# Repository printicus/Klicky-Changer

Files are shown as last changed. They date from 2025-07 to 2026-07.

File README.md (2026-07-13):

# Klicky-Changer 

If you use original KTC from V's github dont go past Klipper v0.13.0-669. For this use the folowing:

```
sudo service klipper stop
cd ~/klipper
git checkout fb57d59ce0aeebfe63d0f7c5d716ee9119faf029
sudo service klipper start
```
After that, if you have a klipper warning, do a "soft reset" not "hard reset", or you will need to reinstall all other addons.

### (fully functional, thing are still being added, modified...)
 
Short demo print featuring [Miniburner XL Toolhead](https://github.com/printicus/For-Voron-Printers/tree/main/MiniBurner_XL_Toolhead).

Test Print (https://www.youtube.com/watch?v=o_eyPX9v53s)

50 toolchanges demo

Test Print (https://youtu.be/J430dFG2X50)

[DISCORD INVITE](https://discord.gg/PGrTdSWV) or [DISCORD CHANNEL](https://discord.com/channels/1119433664799965186/1412843406224523347)

Klicky-Changer is a toolchanger hardware addon for Voron 2.4 and other similar setups, what uses Klicky Probe(or PCB Klicky) as Z probe. Its inspired from the three pin shuttle and backplate interlocking design from [DraftShift Design](https://github.com/DraftShift/StealthChanger) and uses Viesturz's [klipper-toolchanger](https://github.com/viesturz/klipper-toolchanger) software and modified [Klicky-Probe]( https://github.com/jlas1/Klicky-Probe ) configs.

Thanks to the above mentioned sources for my inspiration, without their work my days would be much empty.

This is a ME project. I designet, remixed or modded these files for me, but I uploaded them here, maybe someone will find them interesting and will want to use them. I use Super Slicer as my slicer of choice, wich has an option for "Vertical Hole shrinking compensation" that allows me to tune vertical holes diameter without modifying other dimensions. This will make the vertical holes a bit smaller when my files are used with other slicers, especially for screw holes ment for selftapping. Be aware of that, or parts will break!

I included a file for vertical hole tuning if you want to do that.

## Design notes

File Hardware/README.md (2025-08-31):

# Klicky-Changer hardware parts

Klicky Changer (https://www.youtube.com/watch?v=5xcj8SzUP70)

## Here you can find the designs for the Klicky-Changer hardware parts.

There is a shuttle for using with classic Klicky-Probe and a shuttle for using with PCB Klicky.
The PCB (from the PCK Klicky kit)that has the JST connector must be modified. Because of space constraints the connector must pe removed(just the plastic part), the pins shortened and the wires that come from the pogopins will be soldered direct on the pins(see picture)

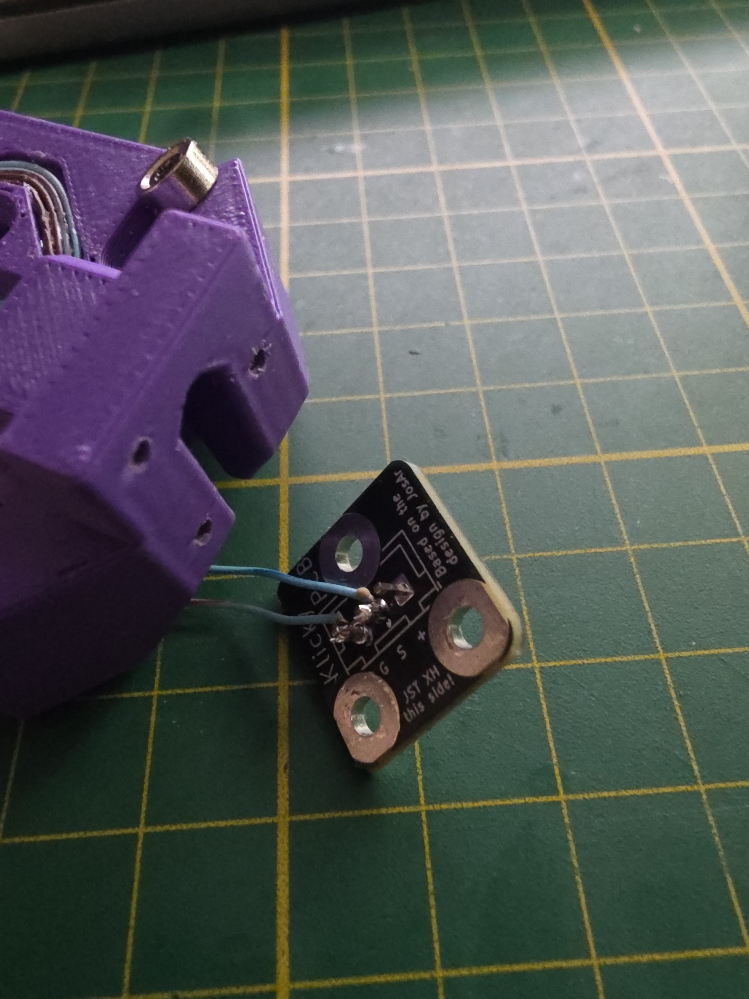
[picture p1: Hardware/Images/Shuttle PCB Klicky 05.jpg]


After some testing I decidet to go with magnets ment to be screwed on, rather than forced into the printed parts. Printed parts tend to loosen over time and the magnets are puled out after repeated use. Glue does not do much.

I gave the option to use double the magnets between the shuttle and backplate. You can choose if you use two pairs or four pairs, depending on what strengt magnets you have. In a normal case, just two magnets on the shuttle, one on each side, and two magnets on the backplate is enough.

The electrical connection between shuttle and backplate is done with pogopins. This is for wireing the Z-probe connection, x-endstop(if you will use it) and for pin detection.

## Pin Detection

For that I use 4 of the 8 pogopins contacts. On the shuttle side solder 4 pogopins together. On the backplate side the corespondent pogopins are soldered 2 and 2. I do this so I will double the contacts uset for tool detection. I dont want after 10 hours printing to get a bad contact and scrap the print. Because I dont use filament detection, the pins for that I use for tool detection. You can use whatever free pins you have on your toolboard.

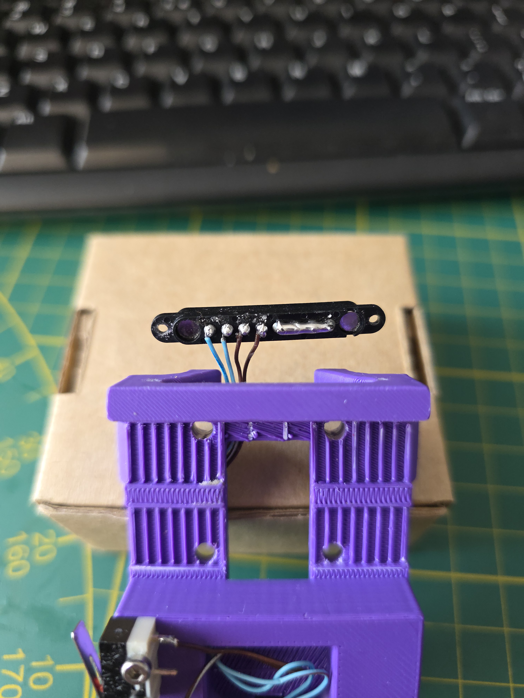
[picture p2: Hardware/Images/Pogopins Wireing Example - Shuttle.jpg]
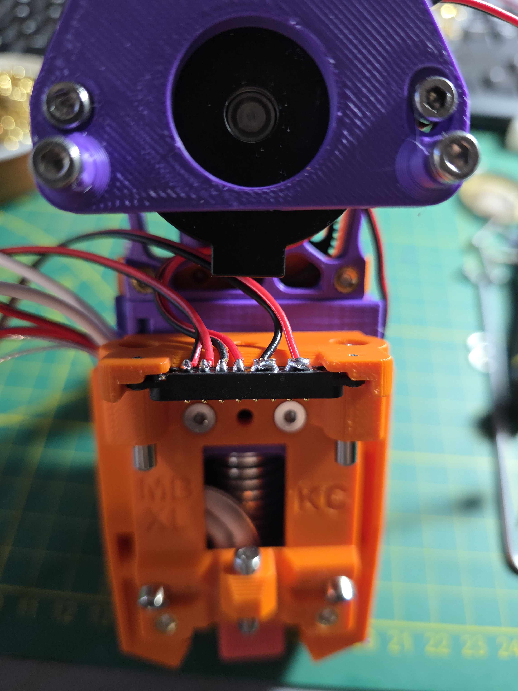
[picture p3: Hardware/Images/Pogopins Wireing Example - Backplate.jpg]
  

## Bom for one shuttle:

- Filament: ABS or ASA
- Endstop switch D2F-L x2 (when used for x endstop the lever stays on, when used for Klicky-Probe the lever must be removed)
- Magnets: 6x3x2mm magnets  x7. This does not include the magnets on the probe itself.
- M2x10  x7 Countersunk Self Tapping Screws for magnets
- Pogopins with 8 contacts. They are sold in pairs. On the shuttle will be used the non springy ones.
- M1.5x4  x2 Self Tapping Screws for the pogopins.
- Thin wires. I've measured them as 0.6mm.
- 4x6x6 Bushings  x3 (Cheap items, buy more than you need and try them out until you find a set that works the best....)

## Bom for probes: BOM can be found on theyr respective Github.

From Klicky Probe github you will need to print the probe and the probe dock(the probe dock will be used allso for PCB-Klicky)
From the PCB-Klicky github you will need to print the probe.

## Links:

- Magnets:  https://www.buyneomagnets.com/p/6mm-dia-x-3mm-thick-with-countersunk-hole-2mm-n35-strong-countersunk-neodymium-disc-magnets-countersunk-ring-rare-earth-magnet

- Endstop switch: https://vi.aliexpress.com/item/1005005222652017.html

- Bushings: https://vi.aliexpress.com/item/1005005335880614.html

    or https://vi.aliexpress.com/item/1005007954250796.html
  
    or https://vi.aliexpress.com/item/1005005924778460.html

- Pogopins I used:  https://vi.aliexpress.com/item/1005006125313623.html  the model I used is "8P with ear 2.54mm". Buy 1-2 pairs extra, maybe, over time the backplate side ones may get bad... not happened to me yet, but nothing is perfect.

- Screws for pogopins: https://vi.aliexpress.com/item/1005003934120055.html

- Screws for magnets - https://vi.aliexpress.com/item/1005006676743568.html

- PCB Klicky kit: https://vi.aliexpress.com/item/1005005467101449.html
- PCB Klicky Github for printed parts: https://github.com/tanaes/whopping_Voron_mods/tree/main/pcb_klicky

- Klicky-Probe Github for printed parts and guides: https://github.com/jlas1/Klicky-Probe

## Recomendet tools

One set of allen keys, Philips small screw-drivers, box cutter, Drill bits starting at 1mm, Side Cutters, pliers, ruler, calipers, etc

Drill Bits Sets: https://vi.aliexpress.com/item/1005004411348630.html
You will need to make shure the holes for the M1.5 and M2 selftapping screws are the rigt size, or parts will break. For the M1.5 screw I use the 1mm drill bit to redrill the hole and for the M2 I use the 1.5mm drill bit.

## Printing

I use primarely SuperSlicer. My designs are made to take advantage of the "Vertical Hole shrinking compensation" setting in that slicer, that lets me tune vertical hole size without altering other dimensions. So if you will slice my files with other slicers, the vertical holes will come out smaller. The holes ment for self tapping screws are the most problematic in this situation. Maybe you will need to redrill them to fit screws trough. I includet a file for tuning the hole size, if you want to use it.

4 walls, 5 tops, 5 bottoms. 40-50% infill. Only pink color allowed.... :D

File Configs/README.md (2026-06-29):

# Configuring Klicky-Changer for Voron 2.4

## Please read all of this first and then start configuring Klicky-Changer.

## KNOWN LIMITATION(AND DANGER):

- Because of how Klicky-Probe software works, the first move when homing after starting the printer, or after the stepper motors disengaging, is the gantry going up by the value of "safe_z", found in **/Klicky-Probe/klicky-variables.cfg** . This will happen once if you use G28(or "home all" buton on your printer web interface), or it will happen twice if you use G28 XY and G28 Z one after annother. So if it happens that the gantry is stoppend and the stepper motors are disengaged close to your printer max Z hight for some reason ( just started the printer, finished print, some errors by docking and undocking, or any other reasons ) do not home the printer or you'll run the risk of going over your Z hight limit and break something. Please manualy move the toolhead to the center of your x-y axis and carrefully ( after making shure no printed parts are on the printer bed ) use the "UNSAFE_LOWER_GANTRY" macro to lower the gantry to a safer hight. The macro will move the gantry down 20mm. So use it to move the gantry to about the half of your printer Z hight, and then home the printer. Dont use the macro if the toolhead is at bed level, it will crash the toolhead and the shuttle in the bed.

- Homing must be in X-Y-Z sequence. Homing Y-X-Z can lead to colision whit the Klicky-Probe Dock or the magnets from the shuttle can drag the Klicky-Probe down from dock and lead to errors and/or crashes.

- The bed mesh "mesh_min" Y distance value should not be smaller than the probe Y offset value ( [tool_probe T(n)] - "y_offset" ). A value of 25 for the "mesh_min" Y will be ok.

- The QGL Y back probe points value ("points:") should not be bigger than your Y max bed size minus the probe Y offset value ( [tool_probe T(n)] - "y_offset" ). A value of (your bed Y size) minus 40 will be ok.

## Klicky-Changer's functions:

- Its a Toolchanger. You can have as many toolheads your printer can fit, and use them for multicolor and multimaterial printing.
- It uses Klicky-Probe (or PCB Klicky) as a Z-Probe for homing, bed meshing and QGL.
- It uses pin detection for knowing what tool is mounted.
- If you have the posibility for homing with every toolhead(if you have sensorless setup, or microswitches for x and y) you can home and start a print with whatever toolhead is on the shuttle. No need to make shure T0 is on the shuttle to home and start printing.

  [My X-endstop solution](../Configs/The%20X-Endstop.md)

## This is how I have configured my printer.

- [Bed Position](Bed_Position.md)
- This is a configuration for "Z-Probe on all tools and fixet docks", with the tool docks on a aluminium profile placed on the front of the printer(or in a door buffer, if you have one). If you want liftbar you must configure that youself, im not familiar with that.
- This configuration steps are for using Klicky-Changer with [MiniBurner XL Toolhead](https://github.com/printicus/For-Voron-Printers/tree/main/MiniBurner_XL_Toolhead). Klicky-Changer can be used with other toolheads to(no limitation there). The main difference will be dock configuration, and you will need to adapt the backplate to your desired toolhead(or ask me to do it...). For that you will need to refer to the specific toolhead you want to use.
- First do the Klicky-Changer configuration as it is. If you decide to do changes in files and/or configs other than what is mentioned in this guide, you may get errors... I run my printer with this configs for a long time now and i got no errors or crashes.
- Homing is handled by Klicky-Probe homing_overide macro. You can find it in **/Klicky-Probe/klicky-macros.cfg**. As it is now, its set for homing with regular microswitches for X and Y. If you want to use sensorless homing you will need to ad macros for that. The macros must be named "_HOME_X" for sensorless X, and "_HOME_Y" for sensorless Y. Allso you must do the rest of the sensorless homing configuration on your hardware and in your printer.cfg.
- After every file modification do a "firmware restart". Until the configuration is finished allways home with T0.

First, please, do a back-up of your configs.
Have the hardware part sorted out(wireing, shuttle, backplates with toolheads, toolheads docks, klicky-probe dock...)

The printer must have klipper and all configs instaled, and functioning as a printer(for best results I recomand a fresh klipper install). For that refer to your Mainboard documentation and your printer manual. If you already have Klicky-Probe(or PCB-Klicky) hardware installed(the probe dock) it will make this setup easier. Delete all klicky-probe files and configs from your printer config folder, Klicky-Changer comes with its own configs for Klicky-Probe. Allso no Kamp or other pluggins for whatever function you have installed. Those can be addet after Klicky-Changer is fully functional, if you still need them. Klicky-Changer comes with tool priming macro includet(N3MI's Prime_Lines macro).

## [Installing](../Configs/Installing.md)

You will need to set the pins in each toolhead configs for the pins of the toolboard atached to it, and ad toolheads configs for all your toolheads. I only posted two as an example.

You will need to set [Klicky-Probe dock position](https://github.com/jlas1/Klicky-Probe/tree/main/Printers/Voron/v1.8_v2.4_Legacy_Trident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) and all the relevant setting for your setup(bed size, etc) in **/Klicky-Probe/klicky-variables.cfg**

## Setting T0 Probe Z-Offset(the paper sheet method):

- You will need to ad in each tool config the probe Y offset ( [tool_probe T(n)] - "y_offset" ). The value for both shuttles(for Klicky-Probe and PCB-Klicky) is **22.45**.

- G28 - QGL - G28(or use the G32 macro includet, it does the same thing, but with fewer probe docking and undocking)
- Make shure the probe is not atachet to the toolhead.
- Move the toolhead to the middle of the bed, imput "G0 Z0" into the console.
- Put a paper sheet on the bed, under the nozzle. Use the Z-Offset controls in your web interface to bring the nozzle down untill it lightly touches the paper. Adjust the z-offset until you feel a small amount of friction when pushing the paper back and forth. The resulted Z-Offset will be a negative number( for example: -4.2 ). You will put that number in your T0 config under "[tool_probe T0]" - "z_offset:", but as a positive number( for example: 4.2).
- Do a one layer print test for fine tunning the first layer z-offset, and adjust the T0 z-offset value in your T0 config file accordingly.

The formula for finding the new value for Z-offset is: the z-offset from the T0 config-(the new z-offset).
For example: the z-offset from the T0 config is 4.2 and the new z offset after adjusting for better first layer is, lets say, -0.12(how it shows in the web interface z-offset). That results in 4.2-(-0.12), and after math rules its 4.2+0.12=4.32 Thats the new value for T0 z-offset.

Value adjusting in the toolheads configs must be done manually, not with the "save config" command.

After you have a first layer to be proud of, write that Z offset value in all your tools configs([tool_probe T(n)] - "z_offset:")
If you will need to again fine tune the T0 z-offset and it will be a different value(usually a very small difference do to the plastic on the touching points between shuttle and backplate settling after repeated toolchanges) you will need to write the new Z-offset value in all tools configs.

## Setting dock position

## Definition: "docked position" is the toolhead position on the shuttle, inserted in the dock in the correct x an y position, with the toolhead magnets close to the dock magnets, but not touching.

After setting T0 Z-offset, and with T0 on the shuttle:
1. G28 - QGL - G28(or use the G32 macro includet, it does the same thing, but with fewer probe docking and undocking)
2. Using the web interface move your toolhead to his designated dock so that it will be in the "docked position", as precise as you can. Write the X and Y coordonates shown in the Toolhead position on your web interface in your T(n)(n = what number toolhead you have on the shuttle) config, under [tool T(n)] section's "params_park...". For Z coordonates you will need to ad 1mm and do the same. 
3. Carefully backup the toolhead from the dock , and lower the gantry to about 50-100 Z position. Do a "Firmware Restart".
4. After restart, with T0 on the shuttle, do a G32. Manually swap T0 with next toolhead that needs dock setting. Go to step 2. If all toolhead have the dock positiom set, go to step 5.

Usually, when all toolheads and docks are the same model, the Y and Z "docked position" for all toolhead should be the same. But dont rely on this...

5. For testing and safety purposes, change the "params_fast_speed" and "params_path_speed" in the /Klipper-Toolchanger/toolchanger.cfg file to a much lover value. Lets say 5000 and 300. Do a "Firmware Restart". After the testing is done you will revert this change.
6. With T0 on the suttle do a G32. When finished, atempt a toolchange by using the Tools macro. Be ready to catch the toolhead if something goes wrong... Adjust the dock position coordonates if needet untill the toolchanges are done whitout problems.

## Setting the other toolheads(T1, T2, etc) g-code z-offset(not T0)

1. With T0 on the shuttle do a G32. Use the tools macro to do a toolchange for the next tool that needs setting the g-code z-offset. Move the tool to the middle of the bed, input on the console G0 Z1. See if the nozzle is touching the bed. If not, use the web interface to move to toolhead down to Z0 in small steps(0.1mm). 
2. If you got to Z0 and the nozzle is not touching the bed, put a piece of paper under the nozzle and use the z-offset controls to lower the nozzle until it touches the paper. Adjust that until you feel a small amount of friction when pushing the paper back and forth. Go to step 4.
3. If the nozzle is touching the bed before you got to Z0, rise the nozzle with the z-offset controls by 0.1 mm, then lover the nozzle with the tool position controls by 0.1mm. Do this until the toolhead is at Z0 and the nozzle does not touch the bed. Go to step 2.
4. The value shown in the web interface under z-offset is the value you must write in your T(n) tool config in [tool T(n)] section under "gcode_z_offset:" This time the value must be writen as shown in the web interface. Do a "Firmware Restart".
5. If all other toolheads have the g-code z-offset set, next step is X and Y gcode offsets. If not, go to step 1.

You must, as with T0, do a one layer print test with each toolhead to fine tune that first layer. The new value shown in the web interface z-offset position must replace the value in that toolhead gcode z-offset setting.
The gcode z-offset value adjusting in the toolheads configs must be done manually, not with the "save config" command.

## [Slicers](../Configs/Slicers.md)

## Setting the toolheads(T1, T2, etc) g-code X and Y offsets.

The X and Y gcode offsets are needet so that all nozzles after T0(T1, T2, etc) are alignet with T0 nozzle.

Guides on how to do that can be found in the links bellow. 

I use a [nozzle camera](https://github.com/printicus/For-Voron-Printers/tree/main/OV9726%20Nozzle%20Camera) and [Axiscope](https://github.com/nic335/Axiscope) to do that.

But there are allot of other methods:

By printing: https://www.printables.com/model/201707-x-y-and-z-calibration-tool-for-idex-dual-extruder

NozzleAllign - https://github.com/viesturz/NozzleAlign

Nudge - https://github.com/zruncho3d/nudge

kTAMV - https://github.com/TypQxQ/kTAMV

In theory, thats it. Your setup my need some adjustments over time, but its ready to print. Good Luck.

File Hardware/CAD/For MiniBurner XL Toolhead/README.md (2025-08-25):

# This are the parts needet to use my toolhead, MiniBurner XL, with Klicky-Changer.

You can find Miniburner XL Toolhead [HERE](https://github.com/printicus/For-Voron-Printers/tree/main/MiniBurner%20XL%20Toolhead).

## BOM for Dock:
- Filament ABS or ASA
- M3 Heat Inserts x2(voron specs)
- 6x3x2 Magnets x4 - N-S oriented all in the same direction. The pairs for this magnets will be on the toolhead
- M2x10 x4 Countersunk Selftapping Screws for magnets
- M3 Hammerhead T-nuts x2
- M3x8 x4
- Silicon for the silicon pad
- 50x10x0.4 spring steel for the silicon pad.

## BOM for Backplate
- Filament ABS or ASA
- M3 Heat Inserts x2(voron specs)
- M3x4x12 Pins x3 - https://vi.aliexpress.com/item/1005007596796680.html
- M3x10 x2 screws - for the upper pins(see CAD)
- M3x8 x1 screw - for the lower pin
- Pogopins - The pair that comes with the one mounted on the shuttle. On the Backplate will be mounted the one with the springy pins. The pogopins have magnets on both ends, and can be paired only in one direction.
- M1.5x4 x2 Self Tapping Screws for pogopins(the same used on the shuttle) - https://vi.aliexpress.com/item/1005003934120055.html
- 6x3x2 Magnets - two with N-S oriented in one direction and two in the other direction(see picture in Images folder)
                https://www.buyneomagnets.com/p/6mm-dia-x-3mm-thick-with-countersunk-hole-2mm-n35-strong-countersunk-neodymium-disc-magnets-countersunk-ring-rare-earth-magnet
- M2x8 x4 Countersunk Self Tapping Screws for magnets - https://vi.aliexpress.com/item/1005006676743568.html

## Printing:

4 walls, 5 Top layers, 5 Bottom layers, 40-50% infill.

Shuttle and Backplate should be printed in the same XY orientation. No mather how good your printer is, there would allways be a size diference between the same dimension on X and Y.

## For the Shuttle and Backplate - The design gave you the option for 4 pairs of magnets, but you should only use them all if your magnets are weak. No need to use 4 pairs of magnets. For normal use two magnets on the shuttle, one on each side, and two on the backplate are enough.

## Using the silicon mold for Miniburner XL toolchanger dock.

Silicon Mold (https://www.youtube.com/watch?v=6CMpIc2Bso8)

Silicon I used: - https://www.amazon.de/dp/B01MZ7EO1V?ref=ppx_yo2ov_dt_b_fed_asin_title&th=1

Its a very high temp resisting silicon. No release agent needed. It does not stick to annything, and can easy be removed. One or two holes drilled in the springsteel strip before molding it in the pad for the dock, will help.

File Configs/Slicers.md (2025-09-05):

# This is how I have configured my slicers

## **My primary Print_Start is in the slicer.**

## - For Super Slicer:

In your "Filament Settings" tab, in "Multimaterial" settings you must have enabled "ramming for multitool setups". This will make restore your tool after a toolchange on the wipe tower and not the printed part. 

In the Printer Setting tab, under Custom G-code:
 - In the "StartG-code" window I have:

```
BED_MESH_CLEAR
G28 x y
Attach_Probe_Lock
G28 z
G90
G0 X30 Y30 Z100 F20000              ; move nozzle away from bed
M190 S[first_layer_bed_temperature] ; wait for bed temp to stabilize
QUAD_GANTRY_LEVEL
G28
BED_MESH_CLEAR
BED_MESH_CALIBRATE ADAPTIVE=1
Dock_Probe_Unlock
G0 X30 Y30 Z100 F20000              ; move nozzle away from bed
PRINT_START TOOL_TEMP={first_layer_temperature[initial_tool]} {if is_extruder_used[0]}T0_TEMP={first_layer_temperature[0]}{endif} {if is_extruder_used[1]}T1_TEMP={first_layer_temperature[1]}{endif} {if is_extruder_used[2]}T2_TEMP={first_layer_temperature[2]}{endif} {if is_extruder_used[3]}T3_TEMP={first_layer_temperature[3]}{endif} {if is_extruder_used[4]}T4_TEMP={first_layer_temperature[4]}{endif} {if is_extruder_used[5]}T5_TEMP={first_layer_temperature[5]}{endif}  BED_TEMP=[first_layer_bed_temperature] TOOL=[initial_tool]
```

 - In the "Tool change G-code" window I have:

```
{if layer_num > 0}
M104 S{temperature[next_extruder]} T[next_extruder] ; set new tool temperature so it can start heating while changing
{else}
M104 S{first_layer_temperature[next_extruder]} T[next_extruder] ; set new tool temperature so it can start heating while changing
{endif}
M106 S0
T[next_extruder]
{if layer_num > disable_fan_first_layers -1}
M106 S{default_fan_speed *2.55}
{endif}
```

This will start preheating your next tool acording to what layer it will be printing. If you have in your slicer different temps for first layer and the other layers it will preheat accordingly. It will also stop the PCF for the toolchange, so it will not interfere with the temp stabilization, and will start the PCF only at the layer that you have it set in the Filament Settings tab, under Cooling, and at the speed you have it set.

## - For Prusa Slicer:

In your "Filament Settings" tab, in "Advanced" settings you must have enabled "ramming for multitool setups". This will make restore your tool after a toolchange on the wipe tower and not the printed part.

In the Printer Setting tab, under Custom G-code:
 - In the "StartG-code" window I have:

```
BED_MESH_CLEAR
G28 x y
Attach_Probe_Lock
G28 z
G90
G0 X30 Y30 Z100 F20000            ; move nozzle away from bed
M190 S[first_layer_bed_temperature] ; wait for bed temp to stabilize
QUAD_GANTRY_LEVEL
G28
BED_MESH_CLEAR
BED_MESH_CALIBRATE ADAPTIVE=1
Dock_Probe_Unlock
G0 X30 Y30 Z100 F20000         ; move nozzle away from bed
PRINT_START TOOL_TEMP={first_layer_temperature[initial_tool]} {if is_extruder_used[0]}T0_TEMP={first_layer_temperature[0]}{endif} {if is_extruder_used[1]}T1_TEMP={first_layer_temperature[1]}{endif} {if is_extruder_used[2]}T2_TEMP={first_layer_temperature[2]}{endif} {if is_extruder_used[3]}T3_TEMP={first_layer_temperature[3]}{endif} {if is_extruder_used[4]}T4_TEMP={first_layer_temperature[4]}{endif} {if is_extruder_used[5]}T5_TEMP={first_layer_temperature[5]}{endif}  BED_TEMP=[first_layer_bed_temperature] TOOL=[initial_tool]
```

 - In the "Tool change G-code" window I have:

```
{if layer_num > 0}
M104 S{temperature[next_extruder]} T[next_extruder] ; set new tool temperature so it can start heating while changing
{else}
M104 S{first_layer_temperature[next_extruder]} T[next_extruder] ; set new tool temperature so it can start heating while changing
{endif}
M106 S0
T[next_extruder]
{if layer_num > disable_fan_first_layers[current_extruder] -1}
M106 S{min_fan_speed[current_extruder] *2.55}
{endif}
```

This will start preheating your next tool acording to what layer it will be printing. If you have in your slicer different temps for first layer and the other layers it will preheat accordingly. It will also stop the PCF for the toolchange, so it will not interfere with the temp stabilization, and will start the PCF only at the layer that you have it set in the Filament Settings tab, under Cooling, and at the speed you have it set.

## - For Orca Slicer:

In your "Printer/Multimaterial" tab the "Enable filament ramming" option must be enabled. In your filament profiles settings "Multimaterial" tab, the option "Enable ramming for multi-tool setups" must be enabled. This will make restore your tool after a toolchange on the wipe tower and not the printed part.

In the Printer Setting tab, under Machine G-code:
 - In the "Machine startG-code" window I have:

```
BED_MESH_CLEAR
G28 x y
Attach_Probe_Lock
G28 z
G90
G0 X30 Y30 Z100 F20000            ; move nozzle away from bed
M190 S[first_layer_bed_temperature] ; wait for bed temp to stabilize
QUAD_GANTRY_LEVEL
G28
BED_MESH_CLEAR
BED_MESH_CALIBRATE ADAPTIVE=1
Dock_Probe_Unlock
G0 X30 Y30 Z100 F20000         ; move nozzle away from bed
PRINT_START TOOL_TEMP={first_layer_temperature[initial_tool]} {if is_extruder_used[0]}T0_TEMP={first_layer_temperature[0]}{endif} {if is_extruder_used[1]}T1_TEMP={first_layer_temperature[1]}{endif} {if is_extruder_used[2]}T2_TEMP={first_layer_temperature[2]}{endif} {if is_extruder_used[3]}T3_TEMP={first_layer_temperature[3]}{endif} {if is_extruder_used[4]}T4_TEMP={first_layer_temperature[4]}{endif} {if is_extruder_used[5]}T5_TEMP={first_layer_temperature[5]}{endif}  BED_TEMP=[first_layer_bed_temperature] TOOL=[initial_tool]
```

- In the "Change filament G-code" window I have:

```
M106 S0
T[next_extruder]
```

This will stop the PCF for the toolchange, so it will not interfere with the temp stabilization, and generate a toolchange command. The slicer does start the fan after the toolchange.

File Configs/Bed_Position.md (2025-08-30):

The printer bed position should be as in front of the printer as possible. It makes it easy to ad accessories in the back of the printer bed(nozzle scrubbers, klicky-probe dock, nozzle probes, etc).

For this you will home your printer, then move your toolhead to Y0. Make a mark on the XY joints printed parts and on the correspondent gantry extrusion, disengage the stepper motors, manualy move the gantry forward untill it touches the front idlers and measure the distance between the mark on the XY joints printed parts and the mark on the gantry extrusion.

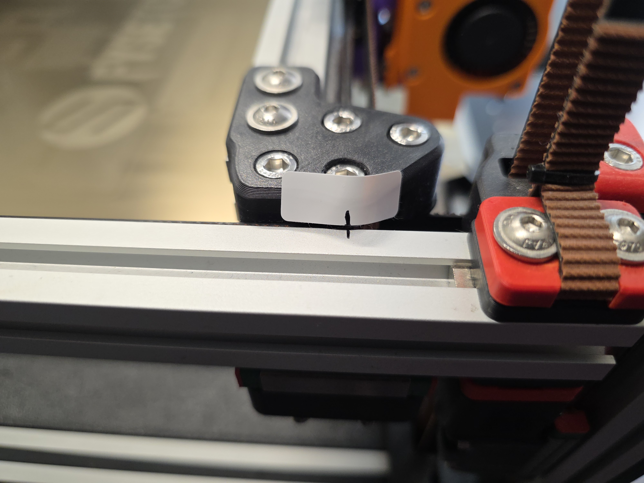
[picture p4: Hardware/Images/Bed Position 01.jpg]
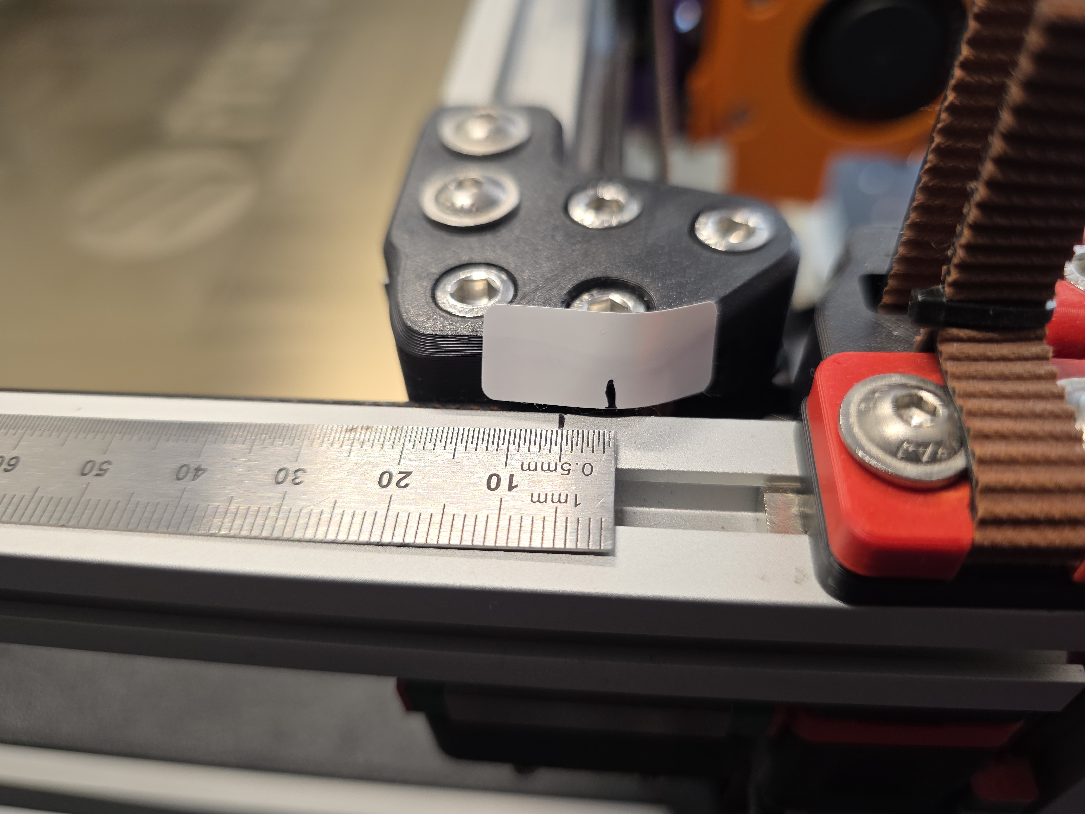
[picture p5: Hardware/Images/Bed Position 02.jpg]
  

That distance measured minus 1mm(you dont want the gantry to slam in the front idlers when going Y0) must be added to the value found in printer.cfg in your Y motor config as "position_endstop:" and "position_max:". All other accessories you allready have configured and depend on Y position must have the Y position corected in their config.

After an "firmware_restart" home the printer, move the toolhead to Y0 and move the bed so that the edge of the bed will coincide with the tip off the nozzle.

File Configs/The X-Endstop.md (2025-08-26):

# The X-Endstop

I have searched a solution for using the microswitch on the shuttle as a X-Endstop for a long time. I did not found the software solution, yet. Klipper does not permit multiple endstops per stepper motor.
So I have gone the hardware route for this:

The original cables for my toolboards where to tick and heavy for what I like, so I build myself other cables. I used for this some PTFE Shielded Cable I found on Aliexpress. The cable I bought has 4 wires(0.35 mm^2) plus the shielding. I used 2 wire for the usb toolboard, 2 wire for x-endstop, I used the shielding for negative voltage and I runned annother PTFE 18AWG wire for plus voltage. As a bonus, the cable is pretty stiff, and, between the stiffnes of the cable and the PTFE tubing for the filament, I dont need to use anny spring wire or flatband to keep the umbilical nice and straight(first asterisk). On the back of the printer I wired all the umbilical x-endstop wires in paralel and connected them to a empty endstop connector on the motherboard. In front, the umbilical x-endstop wires are connected to two of the pogopins that, when atached to the shuttle, are connected to the x-endstop on the shuttle. In this way I have a working X-endstop on the shuttle that works with all toolheads. I hope I did not make annybody dizzy...

Links:
- PTFE Cable 4 wires(0.35 mm^2) - https://vi.aliexpress.com/item/1005007128144063.html
- XT30(2+2)f Connectors - https://vi.aliexpress.com/item/1005008255764206.html
- Extra plus voltage wire - https://vi.aliexpress.com/item/1005001887468108.html
- Molex Connectors - https://vi.aliexpress.com/item/1005005657577507.html

Now, the asterisk:

- First asterisk:

I designet my toolboards mounts so that the cable is tilted towards the back of the printer, so it vill better clear the docks when printing under them. For inforcing that tilt I allso use a 30cm 1.5mm music wire. Pictures are in the Images folder.

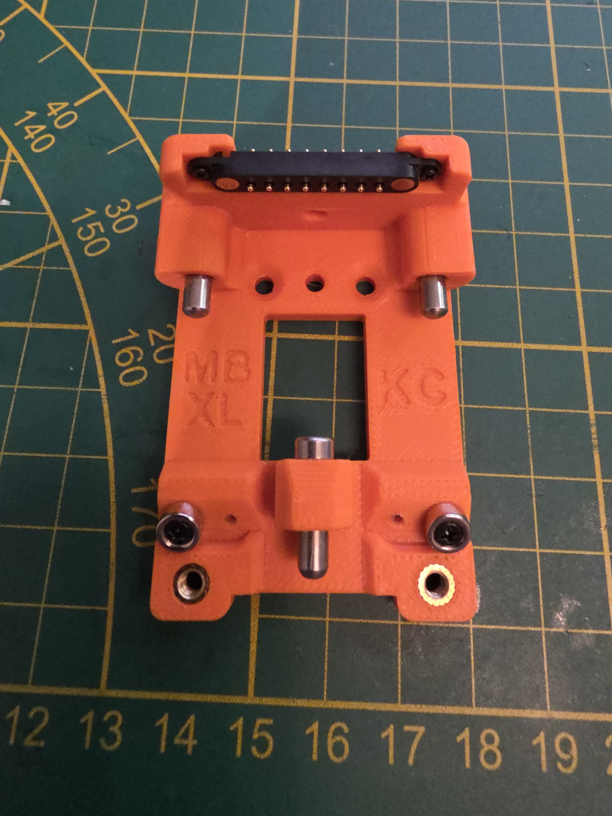
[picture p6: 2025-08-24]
Hardware/CAD/For MiniBurner XL Toolhead/Images/Backplate Miniburner XL 01.jpg

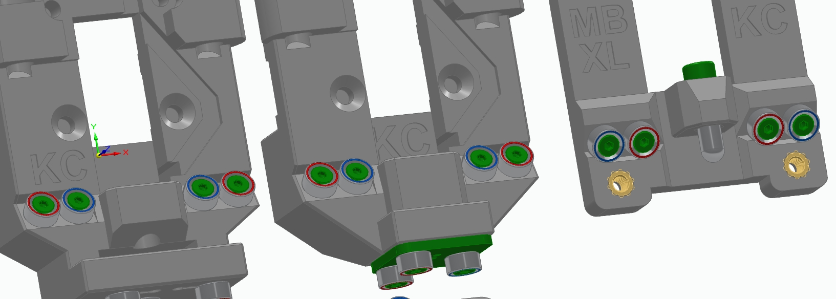
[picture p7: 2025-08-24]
Hardware/Images/Shuttle-Backplate Magnets Orientation.jpg

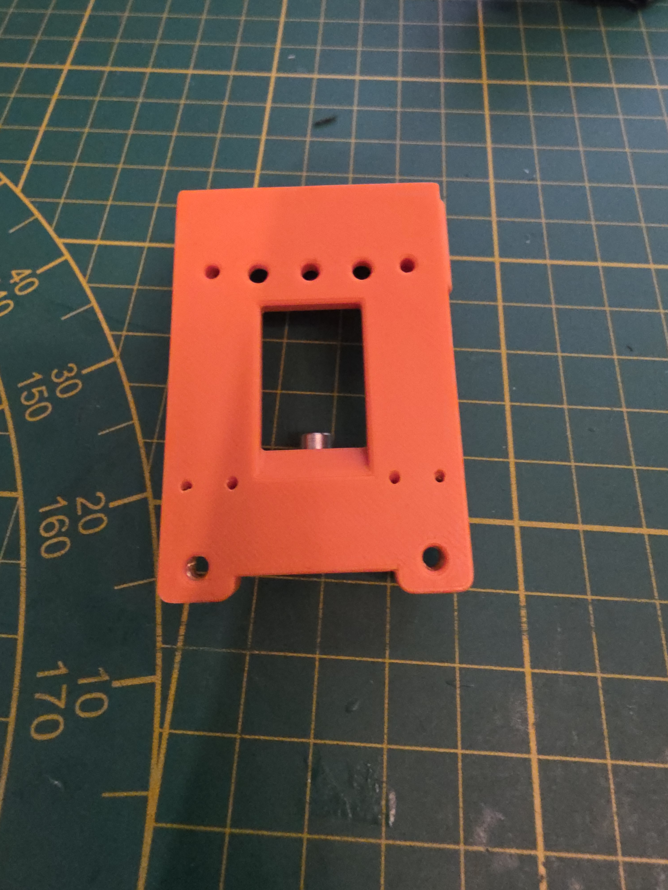
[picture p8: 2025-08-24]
Hardware/CAD/For MiniBurner XL Toolhead/Images/Backplate Miniburner XL 03.jpg

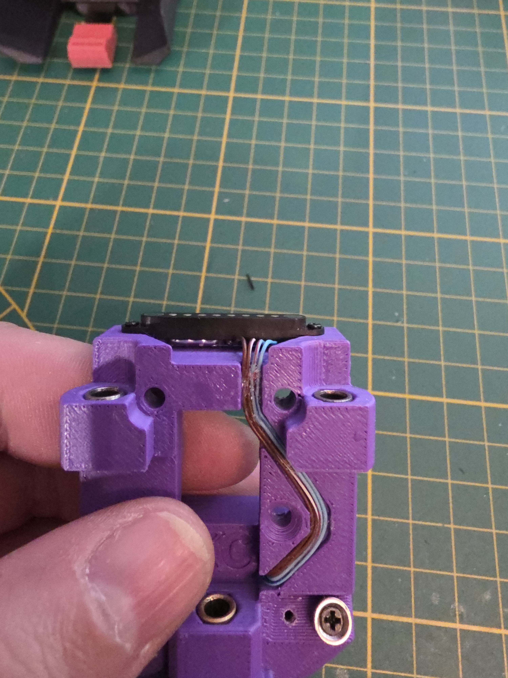
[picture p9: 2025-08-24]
Hardware/Images/Shuttle PCB Klicky 03.jpg

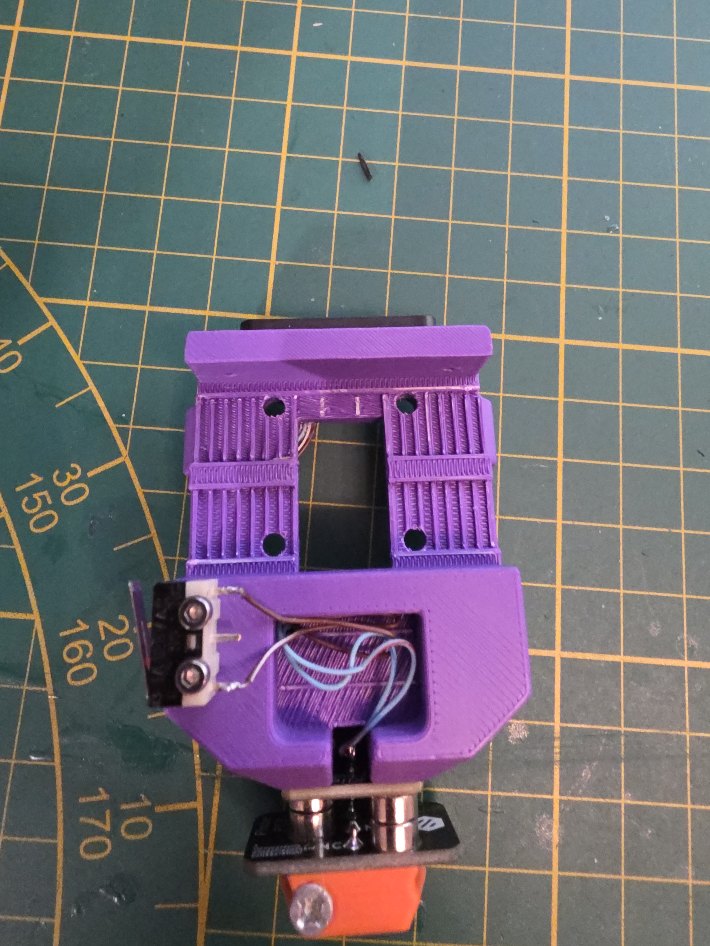
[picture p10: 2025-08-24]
Hardware/Images/Shuttle PCB Klicky 01.jpg

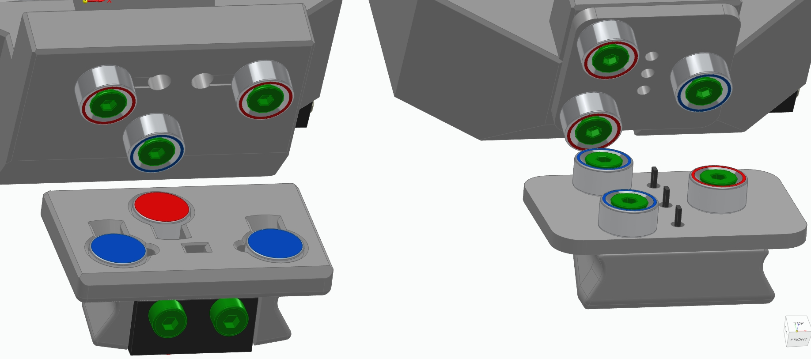
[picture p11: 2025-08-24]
Hardware/Images/Shuttle-Probe Magnets Orientation.jpg

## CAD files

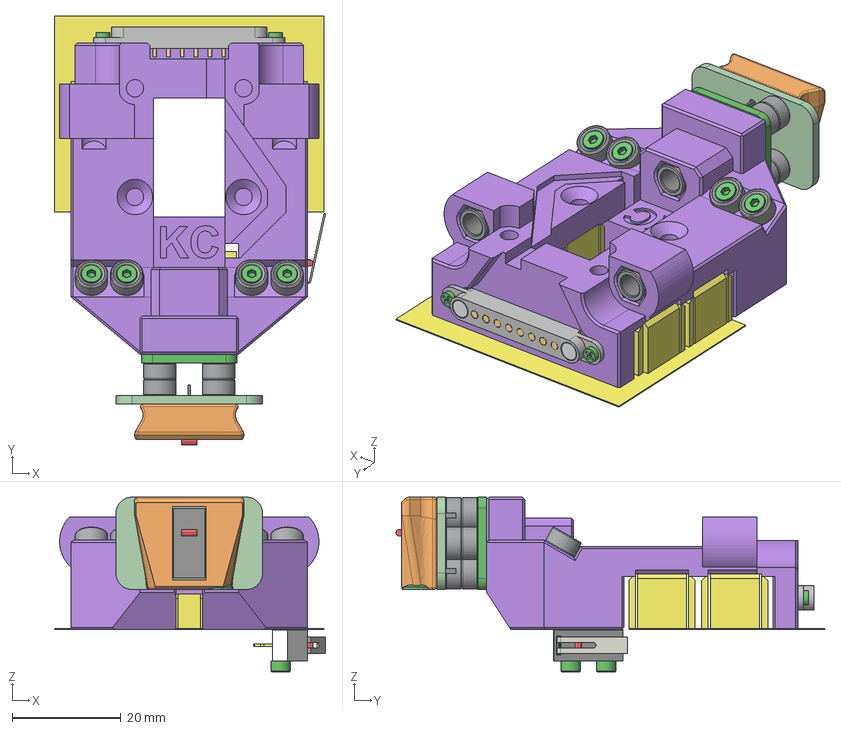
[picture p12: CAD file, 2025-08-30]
Hardware/CAD/KlickyChanger Shuttle for PCB Klicky - 6-9mm - Comlet Assembly.step
49.9 x 79.0 x 32.2 mm
KlickyChanger Shuttle for PCB Klicky - 6-9mm
KlickyChanger Shuttle for PCB Klicky - 6-9mm - Supports
4x6x6mm Bushing x 3
6x3 Magnet With 2mm Coutersunk Hole x 10
pcb shuttle
8 Pin Pogo Pins Connector Female
D2F_Bottom^D2F-L_Straight
D2F_Top^D2F-L_Straight
D2F_Button^D2F-L_Straight
D2F_Pin^D2F-L_Straight x 4
D2F_Hinge^D2F-L_Straight
M2x10mm - Selftapping Screw Countersunk x 7
M2x10 Selftapping screw x 2
M1.5x4 Selftapping Screw x 2
pcb probe
D2F_switch
printed_part v2 - M3 screw
M2x8mm - Selftapping Screw Countersunk x 3
M3x6 hex countersunk-head screw

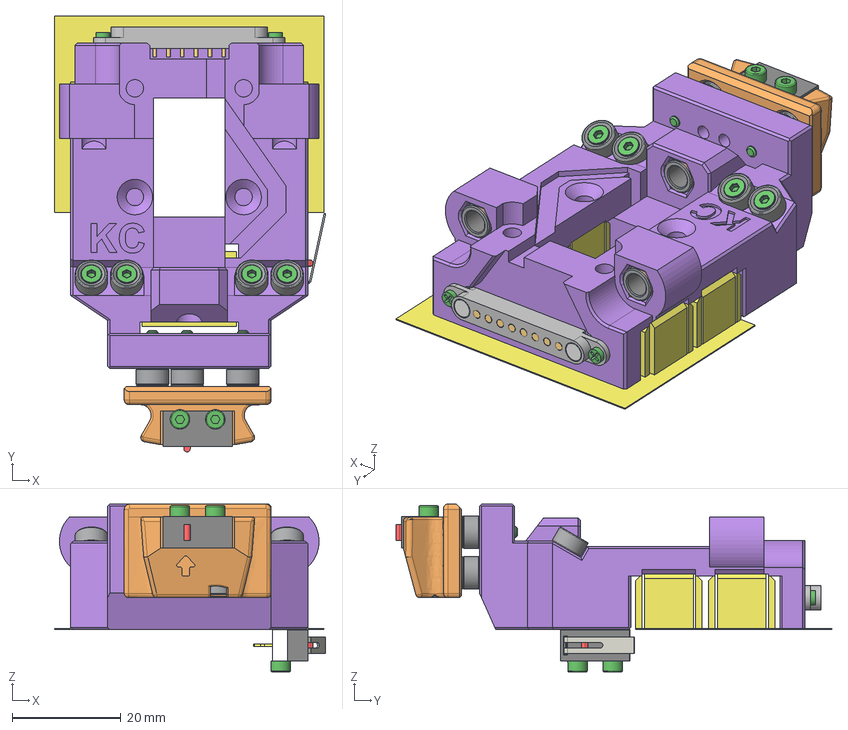
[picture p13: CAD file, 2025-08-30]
Hardware/CAD/KlickyChanger Shuttle for Klicky-Probe - 6-9mm - Complet Assembly.step
49.9 x 80.2 x 30.9 mm
KlickyChanger Shuttle for Klicky-Probe - 6-9mm
KlickyChanger Shuttle for Klicky-Probe - 6-9mm - Supports
4x6x6mm Bushing x 3
KlickyProbe_v2
D2F_ACTUATOR
D2F_BASE
6x3 Magnet x 4
M2x10 Selftapping screw x 4
D2F_Bottom^D2F-L_Straight
D2F_Top^D2F-L_Straight
D2F_Button^D2F-L_Straight
D2F_Pin^D2F-L_Straight x 4
D2F_Hinge^D2F-L_Straight
6x3 Magnet With 2mm Coutersunk Hole x 7
8 Pin Pogo Pins Connector Female
M2x10mm - Selftapping Screw Countersunk x 7
M1.5x4 Selftapping Screw x 2

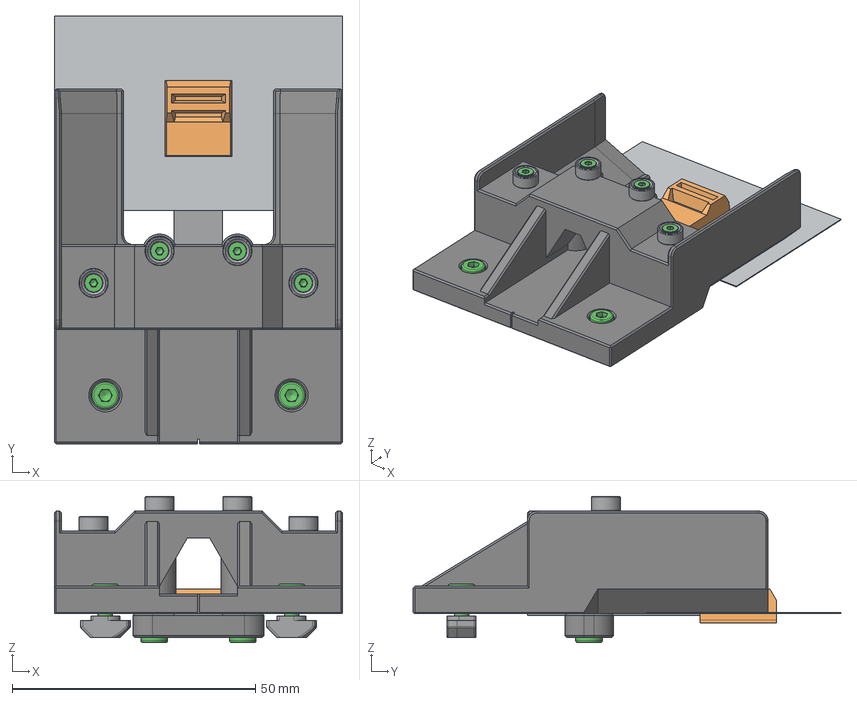
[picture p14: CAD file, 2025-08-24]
Hardware/CAD/For MiniBurner XL Toolhead/MiniBurner XL Dock Assembly.step
59.3 x 88.0 x 30.0 mm
Miniburner XL Dock
Miniburner XL Dock - Brim
6x3 Magnet With 2mm Coutersunk Hole x 4
Heat Insert M3 Short 5x4 x 2
M2x10mm - Selftapping Screw Countersunk x 4
M3x8 hex socket cap screw x 4
M3 Hammerhead T-Nut x 2
SpringSteel Holder
Silicon Pad
SpringSteel

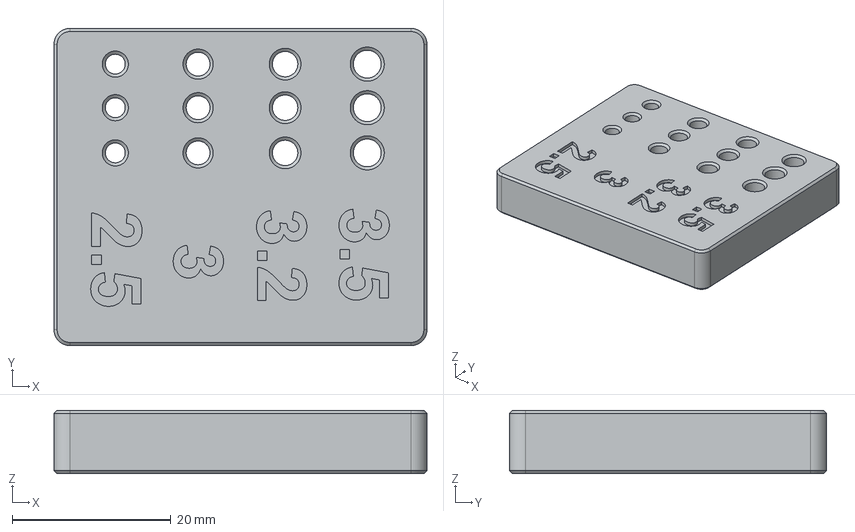
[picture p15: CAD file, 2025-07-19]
Hardware/@-Vertical-Hole-Calibration/Hole Calibration.step
47.0 x 40.0 x 8.00 mm

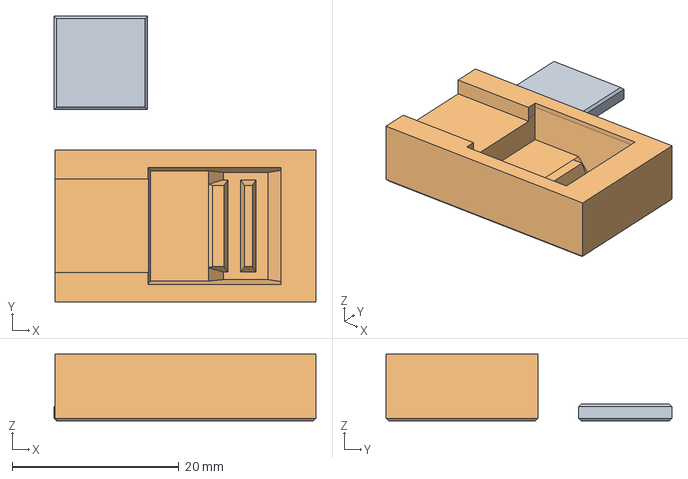
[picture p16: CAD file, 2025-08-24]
Hardware/CAD/For MiniBurner XL Toolhead/Silicon Pad Mold.step
31.4 x 34.3 x 8.00 mm

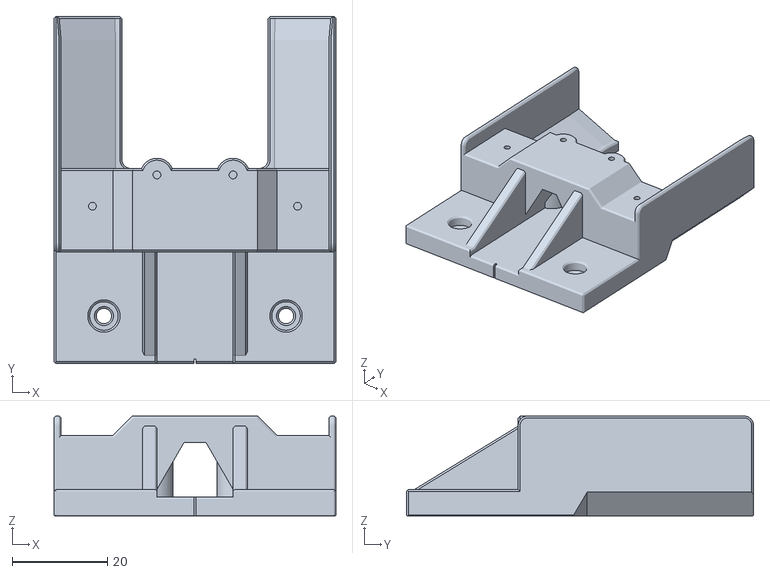
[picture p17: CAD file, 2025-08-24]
Hardware/STL/For MiniBurner XL Toolhead/Miniburner XL Dock.stl
59.3 x 73.0 x 21.0

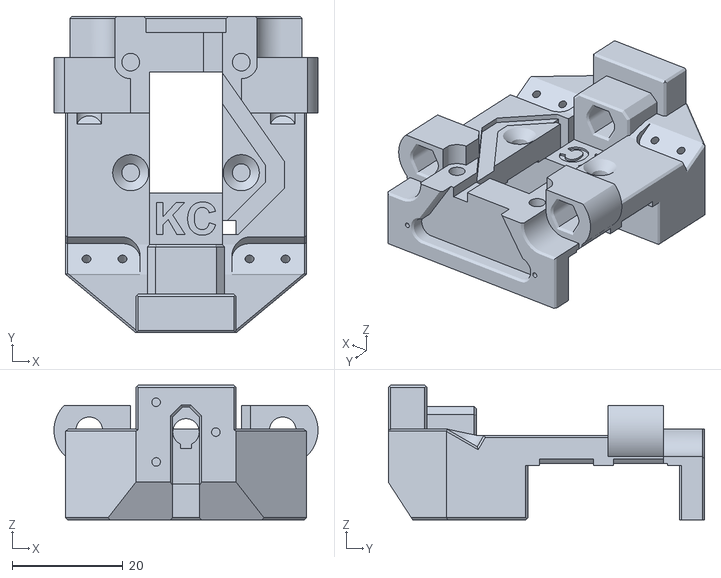
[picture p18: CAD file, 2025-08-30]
Hardware/STL/KlickyChanger Shuttle for PCB Klicky - 6-9mm.stl
47.8 x 57.3 x 24.4

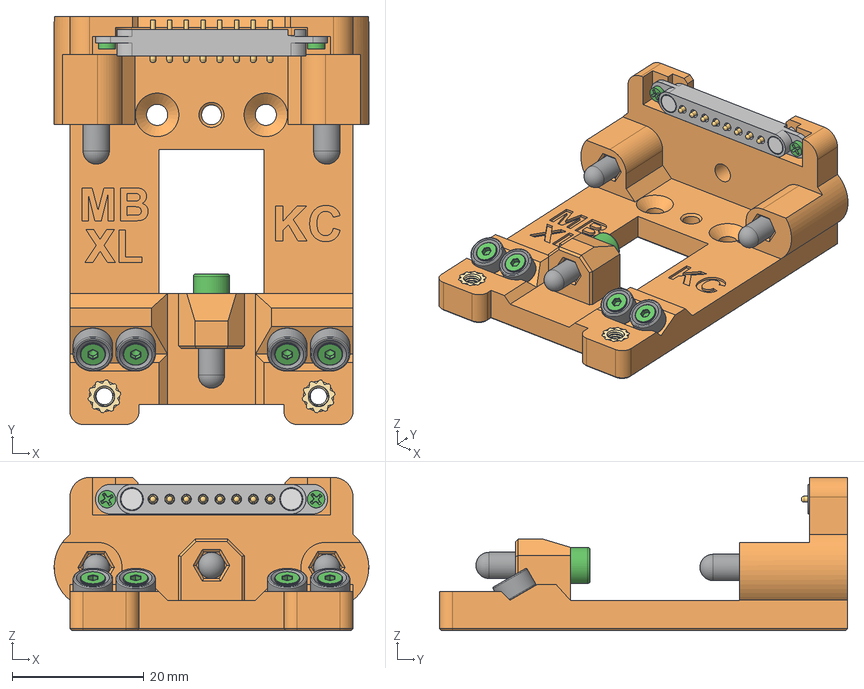
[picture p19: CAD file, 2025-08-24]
Hardware/CAD/For MiniBurner XL Toolhead/KlickyChanger - Miniburner XL Backplate.step
47.7 x 61.9 x 23.2 mm
KlickyChanger - Miniburner XL Backplate
4x12mm Pin x 3
6x3 Magnet With 2mm Coutersunk Hole x 4
M3x10 hex socket cap screw x 2
M3x8 hex socket cap screw
M2x8mm - Screw Countersunk x 4
Heat Insert M3 Short 5x4 x 2
8 Pin Pogo Pins Connector Male
M1.5x4 Selftapping Screw x 2

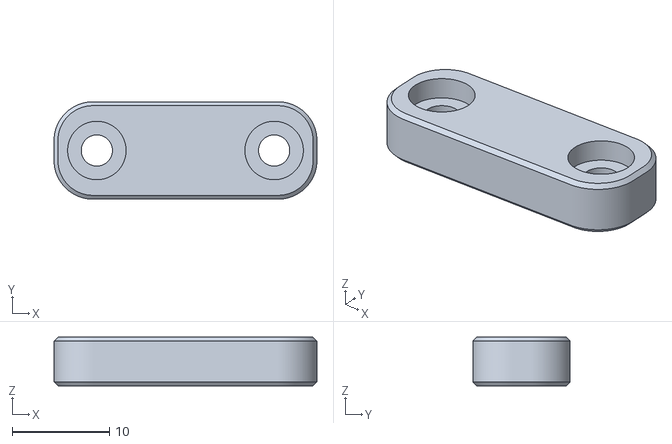
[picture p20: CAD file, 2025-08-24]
Hardware/STL/For MiniBurner XL Toolhead/SpringSteel Holder.stl
27.0 x 10.0 x 5.00

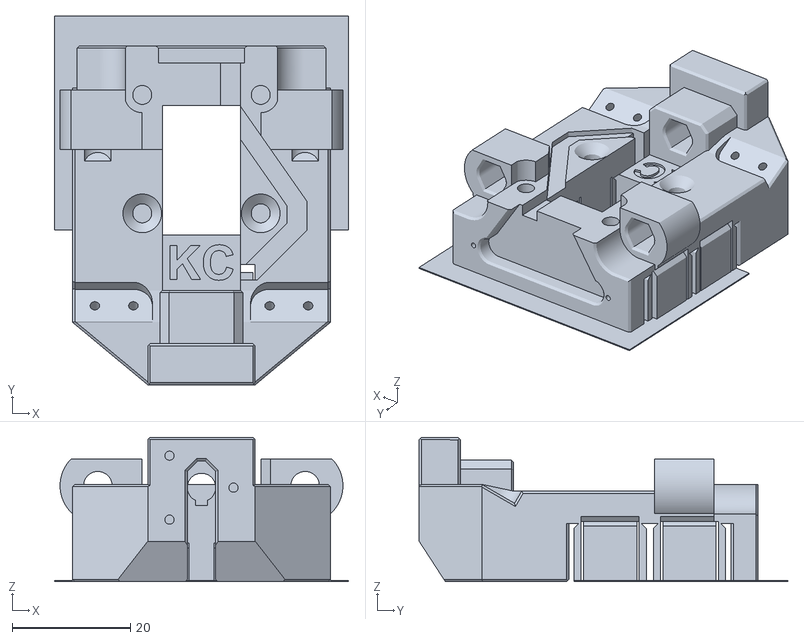
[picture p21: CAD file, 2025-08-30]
Hardware/STL/KlickyChanger Shuttle for PCB Klicky - 6-9mm - With Supports.stl
49.6 x 62.3 x 24.4

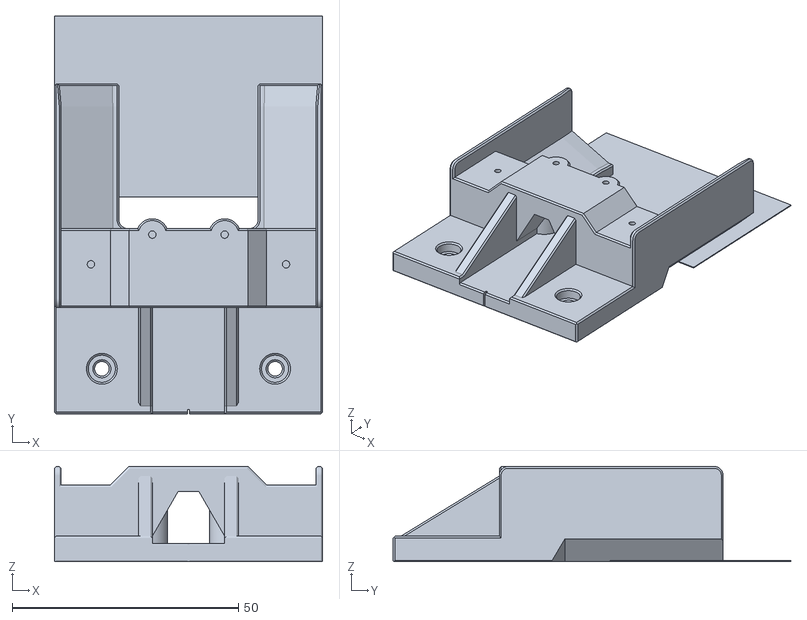
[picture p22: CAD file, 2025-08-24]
Hardware/STL/For MiniBurner XL Toolhead/MiniBurner XL Dock With Brim.stl
59.3 x 88.0 x 21.0

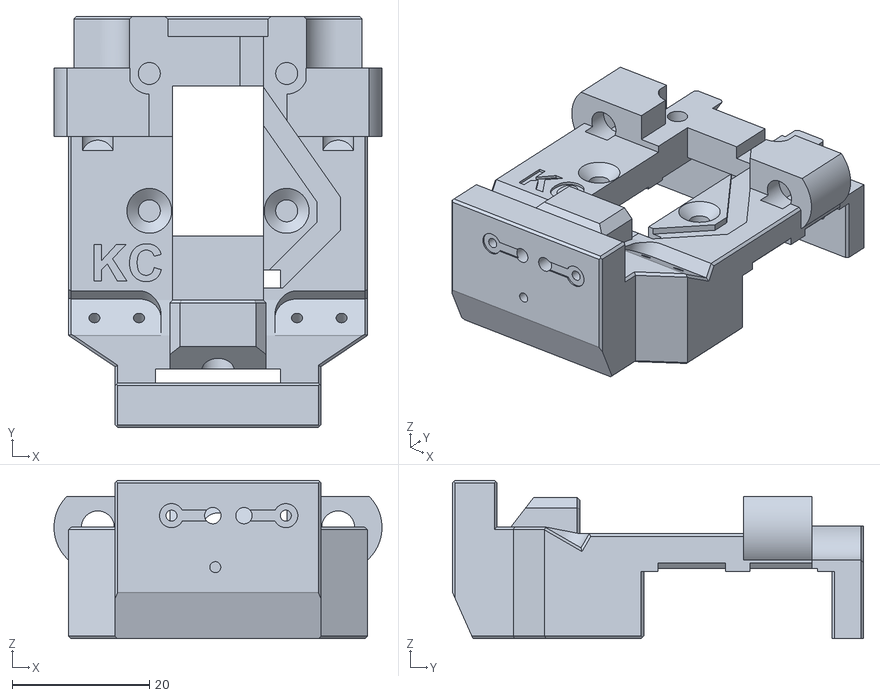
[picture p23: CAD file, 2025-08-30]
Hardware/STL/KlickyChanger Shuttle for Klicky-Probe - 6-9mm.stl
47.8 x 59.9 x 23.1

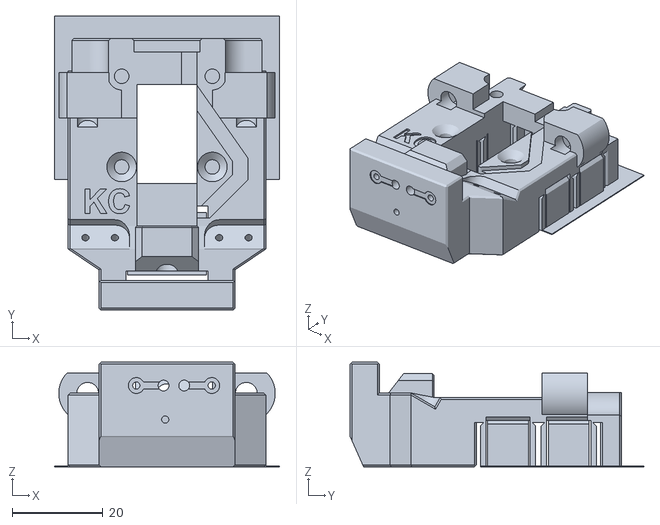
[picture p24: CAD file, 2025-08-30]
Hardware/STL/KlickyChanger Shuttle for Klicky-Probe - 6-9mm - With Supports.stl
49.6 x 64.9 x 23.1

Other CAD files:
Hardware/@-Vertical-Hole-Calibration/Hole Calibration.stl
Hardware/STL/For MiniBurner XL Toolhead/KlickyChanger - Miniburner XL Backplate.stl
Hardware/STL/For MiniBurner XL Toolhead/Silicon Pad Mold.stl

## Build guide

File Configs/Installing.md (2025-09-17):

SSH into your printer and run the installation script for the Klipper-Toolchanger plugin using the following command:
```
wget -O - https://raw.githubusercontent.com/printicus/Klipper-Toolchanger-for-Klicky-Changer/main/install.sh | bash
```
This script will download the Klipper-Toolchanger plugin to your RaspberryPi home directory, and symlink the files in the Klipper extra folder.

- Copy "Klicky-Probe", "Klipper-Toolchanger" and "Toolheads" folders from this repo to your printer config folder.
- Copy "My_MACROS.cfg" and "prime_lines.cfg" to your printer config folder.
- Ad the lines from this "printer.cfg" to your "printer.cfg". Use these macros to replace your printer.cfg macros.
- Delete, or comment out, the [probe] section from your printer.cfg file. Each toolhead config file will have its own probe section.
- Reboot your printer

Optional, ad this to your moonraker.conf to enable automatic updates:

```
[update_manager klipper-toolchanger]
type: git_repo
channel: dev
path: ~/klipper-toolchanger
origin: https://github.com/printicus/Klipper-Toolchanger-for-Klicky-Changer.git
managed_services: klipper
primary_branch: main
```

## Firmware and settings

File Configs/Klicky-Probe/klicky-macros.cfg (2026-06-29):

# This macro was provided by discord user Garrettwp to whom i give my thanks for sharing it with me.
# I have tweaked it a lot.
# They are based on the great Annex magprobe dockable probe macros "#Originally developed by Mental,
# modified for better use on K-series printers by RyanG and Trails", kudos to them.
# That macro as since evolved into a klipper plugin that currently is pending inclusion in klipper,
# more information here, https://github.com/Annex-Engineering/Quickdraw_Probe/tree/main/Klipper_Macros
# User richardjm revised the macro variables and added some functions
# User sporkus added led status notifications
# Thanks to all who helped,
# by standing on the shoulders of giants, lets see if we can see further
#
# the home for the original version of this file is https://github.com/jlas1/Klicky-Probe
#
# some changes have been made for use with a toolchanger setup
#
# the current home for this version is https://github.com/printicus/Klicky-Changer

[respond]

[gcode_macro _Probe_Variables]
variable_probe_attached:            False
variable_probe_state:               False
variable_probe_lock:                False
variable_probe_z_homed:             False
variable_z_endstop_x:               0
variable_z_endstop_y:               0
gcode:


#checks if the variable definitions are up to date
[gcode_macro _klicky_check_variables_version]
gcode:
    {% set version = printer["gcode_macro _User_Variables"].version|default(0) %}

    {% if version != 1 %}
        { action_raise_error("Please update your klicky variables, there are some functionality changes") }
    {% endif %}

[gcode_macro _KlickyDebug]
gcode:
    {% set message  = params.MSG %}
    {% set debug = printer["gcode_macro _User_Variables"].debug|default(False) %}

    {% if debug %}
        { action_respond_info(message) }
    {% endif %}


[gcode_macro _exit_point]
gcode:
    {% set function  = 'pre_' ~ params.FUNCTION %}
    {% set move  = params.MOVE|default(0) %}
    {% set speed = printer["gcode_macro _User_Variables"].travel_speed %}

    # mandatory to save the new safe position
    M400
    SET_VELOCITY_LIMIT ACCEL={printer.configfile.settings.printer.max_accel}
    RESTORE_GCODE_STATE NAME={function} MOVE={move} MOVE_SPEED={speed}


[gcode_macro _entry_point]
gcode:
    {% set function  = 'pre_' ~ params.FUNCTION %}
    {% set move_accel = printer["gcode_macro _User_Variables"].move_accel|default(1000) %}
    # mandatory to save the new safe position
    M400
    SAVE_GCODE_STATE NAME={function}
    # removes the Z offset for better bed based docking
    SET_GCODE_OFFSET Z=0
    # all the macros initially assume absolute positioning
    G90
    # set a safe(sane) Acceleration
    SET_VELOCITY_LIMIT ACCEL={move_accel}

[gcode_macro _Homing_Variables]
gcode:
    {% set reset  = params.RESET|default(0) %}
    {% if reset %}
        SET_GCODE_VARIABLE MACRO=_Probe_Variables VARIABLE=probe_lock VALUE={ False }
    {% endif %}

##########################
# Attach probe and lock it
[gcode_macro Attach_Probe_Lock]
description: Attaches Klicky Probe, can only be docked after unlocking
gcode:
    Attach_Probe
    _Probe_Lock

########################
# Dock probe and lock it
[gcode_macro Dock_Probe_Unlock]
description: Docks Klicky Probe even if it was locked
gcode:
    _Probe_Unlock
    Dock_Probe

##############
# Unlock Probe
[gcode_macro _Probe_Unlock]
description: Unlocks Klicky Probe state
gcode:
    _KlickyDebug msg="_Probe_Lock setting probe_lock variable to False"
    SET_GCODE_VARIABLE MACRO=_Probe_Variables VARIABLE=probe_lock VALUE={ False }

############
# Lock Probe
[gcode_macro _Probe_Lock]
description: Locks Klicky Probe state
gcode:
    _KlickyDebug msg="_Probe_Lock setting probe_lock variable to True"
    SET_GCODE_VARIABLE MACRO=_Probe_Variables VARIABLE=probe_lock VALUE={ True }

###################
# Klicky Dock Servo Deploy

[gcode_macro _DeployKlickyDock]
description: Deploys Klicky servo-controlled dock
gcode:
    {% set enable_dock_servo = printer["gcode_macro _User_Variables"].enable_dock_servo|default(False) %}
    {% set servo_delay = printer["gcode_macro _User_Variables"].servo_delay|default(1000)|int %}
    {% set servo_name = printer["gcode_macro _User_Variables"].servo_name %}
    {% set servo_deploy = printer["gcode_macro _User_Variables"].servo_deploy|default(360)|float %}

    #wait for all the moves to complete
    M400
    {% if enable_dock_servo != False %}
        _KlickyDebug msg="_DeployKlickyDock Klicky servo configuration enabled"
        {% if servo_deploy == 360 %}
            { action_raise_error("Klicky: servo active on klicky-variables, but no servo deploy angle specified") }
        {% endif %}
        _KlickyDebug msg="_DeployKlickyDock SET_SERVO SERVO={servo_name|string} ANGLE={servo_deploy}"
        SET_SERVO SERVO={servo_name|string} ANGLE={servo_deploy}
        M400
        G4 P{servo_delay}
        _KlickyDebug msg="_DeployKlickyDock SET_SERVO SERVO={servo_name|string} WIDTH=0"
        SET_SERVO SERVO={servo_name|string} WIDTH=0
    {% elif printer["gcode_macro _DeployDock"] is defined %}
        _KlickyDebug msg="_DeployKlickyDock calling _DeployDock"
        _DeployDock
    {% endif %}

####################
# Dock Servo Retract

[gcode_macro _RetractKlickyDock]
description: Retracts Klicky servo-controlled dock
gcode:
    {% set enable_dock_servo = printer["gcode_macro _User_Variables"].enable_dock_servo|default(False) %}
    {% set servo_delay = printer["gcode_macro _User_Variables"].servo_delay|default(1000)|int %}
    {% set servo_name = printer["gcode_macro _User_Variables"].servo_name %}
    {% set servo_retract = printer["gcode_macro _User_Variables"].servo_retract|default(360)|float %}

    #wait for all the moves to complete
    M400
    {% if enable_dock_servo != False %}
        _KlickyDebug msg="_RetractKlickyDock Klicky servo configuration enabled"
        {% if servo_retract == 360 %}
            { action_raise_error("Klicky: servo active on klicky-variables, but no servo retract angle specified") }
        {% endif %}
        _KlickyDebug msg="_RetractKlickyDock SET_SERVO SERVO={servo_name|string} ANGLE={servo_retract}"
        SET_SERVO SERVO={servo_name|string} ANGLE={servo_retract}
        M400
        G4 P{servo_delay}
        _KlickyDebug msg="_RetractKlickyDock SET_SERVO SERVO={servo_name|string} WIDTH=0"
        SET_SERVO SERVO={servo_name|string} WIDTH=0
    {% elif printer["gcode_macro _RetractDock"] is defined %}
        _KlickyDebug msg="_RetractKlickyDock calling _RetractDock"
        _RetractDock
    {% endif %}
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

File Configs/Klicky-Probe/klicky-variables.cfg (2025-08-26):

# This macro was provided by discord user Garrettwp to whom i give my thanks for sharing it with me.
# I have tweaked it a lot.
# They are based on the great Annex magprobe dockable probe macros "#Originally developed by Mental,
# modified for better use on K-series printers by RyanG and Trails", kudos to them.
# That macro as since evolved into a klipper plugin that currently is pending inclusion in klipper,
# more information here, https://github.com/Annex-Engineering/Quickdraw_Probe/tree/main/Klipper_Macros
# User richardjm revised the macro variables and added some functions, thanks a lot
# by standing on the shoulders of giants, lets see if we can see further
#
# the 1000 values below is to give an error instead of doing something wrong, hopefully, this won't be used is a printer larger than 1 meter
#
# the home for the original version of this file is https://github.com/jlas1/Klicky-Probe
#
# some changes have been made for use with a toolchanger setup
#
# the current home for this version is https://github.com/printicus/Klicky-Changer

[gcode_macro _User_Variables]
variable_verbose:             True    # Enable verbose output
variable_debug:              False    # Enable Debug output
variable_travel_speed:         200    # how fast all other travel moves will be performed when running these macros
variable_move_accel:          1000    # how fast should the toolhead accelerate when moving
variable_dock_speed:            50    # how fast should the toolhead move when docking the probe for the final movement
variable_release_speed:         75    # how fast should the toolhead move to release the hold of the magnets after docking
variable_z_drop_speed:          20    # how fast the z will lower when moving to the z location to clear the probe

variable_safe_z:                25    # Minimum Z for attach/dock and homing functions
# if true it will move the bed away from the nozzle when Z is not homed
variable_enable_z_hop:        True    # set this to false for beds that fall significantly under gravity (almost to Z max)

variable_max_bed_y:            350    # maximum Bed size avoids doing a probe_accuracy outside the bed
variable_max_bed_x:            350    # maximum Bed size avoids doing a probe_accuracy outside the bed

# if a separate Z endstop switch is in
# use, specify the coordinates of the switch here (Voron).
# Set to 0 to have the probe move to center of bed
variable_z_endstop_x:            0
variable_z_endstop_y:            0

#Check the printer specific documentation on klipper Dock/Undock configuration, these are dummy values
#dock location
variable_docklocation_x:      53.5    # X Dock position
variable_docklocation_y:       357    # Y Dock position
variable_docklocation_z:      -128    # Z dock position (-128 for a gantry/frame mount)

#The following variables are used if the dock is deployed and retracted via a servo motor
variable_enable_dock_servo:  False    # Set to true if your klicky dock is servo-controlled
variable_servo_name:        'NAME'    # The name of the dock servo defined in printer.cfg under [servo]
variable_servo_deploy:          10    # This EXAMPLE is the value used to deploy the servo fully
variable_servo_retract:         11    # This EXAMPLE is the value used to retract the servo fully (initial_angle in [servo] config)
variable_servo_delay:          250    # This is a delay to wait the servo to reach the requested position, be carefull with high values

#Dock move, final toolhead movement to release the probe on the dock
#it's a relative move
Variable_dockmove_x:             40
Variable_dockmove_y:             0
Variable_dockmove_z:             0

#Attach move. final toolhead movement to attach the probe on the mount
#it's a relative move
Variable_attachmove_x:           0
Variable_attachmove_y:           35
Variable_attachmove_z:           0

#Umbilical to help untangle the umbilical in difficult situations
variable_umbilical:          False    # should we untangle the umbilical
variable_umbilical_x:           15    # X umbilical position
variable_umbilical_y:           15    # Y umbilical position

# location to park the toolhead
variable_park_toolhead:      False    # Enable toolhead parking
variable_parkposition_x:       125
variable_parkposition_y:       125
variable_parkposition_z:        30    # if you use -128 the "_Park_Toolhead" macro will use the current z value

variable_version:                1    # Helps users to update the necessary variables, do not update if the variables above are not updated

#Below this remark, you normally do not need to configure
#Attach move2
Variable_attachmove2_x:          0    # intermediate toolhead movement to attach
Variable_attachmove2_y:          0    # the probe on the dock
Variable_attachmove2_z:          0    # (can be negative)

variable_home_backoff_x:        10    # how many mm to move away from the X endstop after homing X
                                      # this is useful for the voron v0 to enable the toolhead to move out of the way to allow an unstricted Y homing
variable_home_backoff_y:        10    # how many mm to move away from the Y endstop after homing Y

variable_override_homing:       ''    # configures what axis to home first
                                      #  '' = default klicky behavior (tries to avoid the hitting the dock)
                                      # 'X' = forces X to home first
                                      # 'Y' = forces Y to home first
                                      
variable_dock_on_zhome:       True    # docks the probe on Z Homing if not necessary (avoids hitting the bed on some printers                                      

# Do not modify below
gcode:
    {% set Mx = printer['configfile'].config["stepper_x"]["position_max"]|float %}
    {% set My = printer['configfile'].config["stepper_y"]["position_max"]|float %}
    {% set Ox = printer.tool_probe_endstop.active_tool_probe_x_offset|float %}
    {% set Oy = printer.tool_probe_endstop.active_tool_probe_y_offset|float %}
    {% set Oz = printer.tool_probe_endstop.active_tool_probe_z_offset|float %}

    # If x, y coordinates are set for z endstop, assign them
    {% if z_endstop_x != 0 or z_endstop_y != 0 %}
        SET_GCODE_VARIABLE MACRO=_Probe_Variables VARIABLE=z_endstop_x VALUE={ z_endstop_x }
        SET_GCODE_VARIABLE MACRO=_Probe_Variables VARIABLE=z_endstop_y VALUE={ z_endstop_y }

    # if no x, y coordinates for z endstop, assume probe is endstop and move toolhead to center of bed
    {% else %}
        SET_GCODE_VARIABLE MACRO=_Probe_Variables VARIABLE=z_endstop_x VALUE={ (Mx * 0.5) - Ox }
        SET_GCODE_VARIABLE MACRO=_Probe_Variables VARIABLE=z_endstop_y VALUE={ (My * 0.5) - Oy }
    {% endif %}

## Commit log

2025-08-26 Update The X-Endstop.md
2025-08-30 Minor Changes
    [KlickyChanger Shuttle for Klicky-Probe - 6-9mm - Complet Assembly.step, KlickyChanger Shuttle for PCB Klicky - 6-9mm - Comlet Assembly.step]
